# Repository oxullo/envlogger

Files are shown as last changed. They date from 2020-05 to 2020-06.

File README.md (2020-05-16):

# ENVLogger

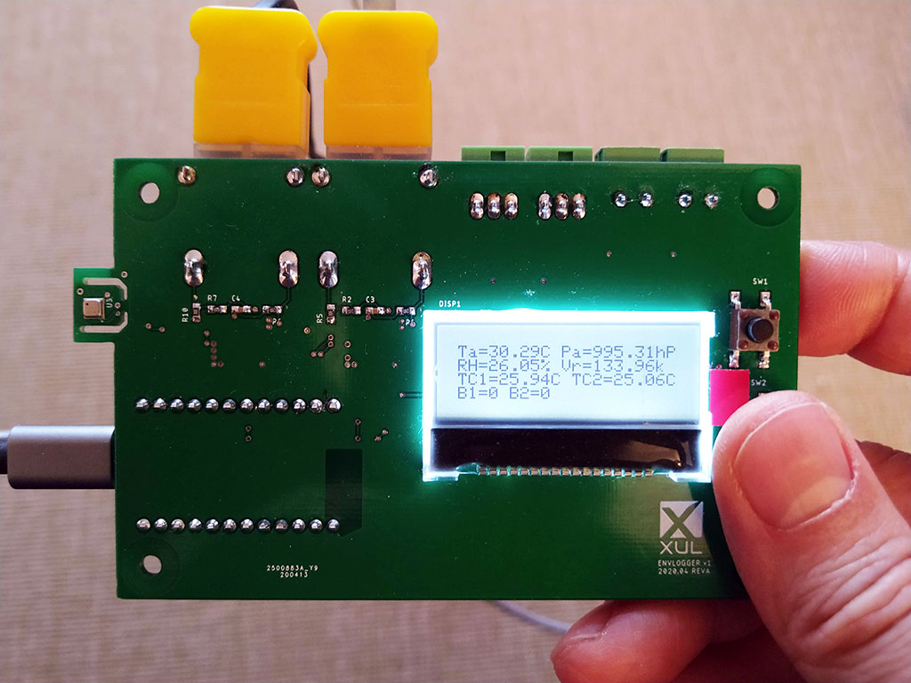
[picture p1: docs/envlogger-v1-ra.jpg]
ENVLogger


Versatile hardware for logging/controlling environmental conditions.

Currently equipping:

* 2x Type-K Thermocouples EMF to digital converters
* Local Bosch-Sensortec BME680 environmental sensor
	* Temperature
	* Humidity
	* Atmospheric pressure
	* Volatile organic compounds
* 2x generic I/Os for additional 1-wire sensors (eg: DS1820B)
* 2x open-drain outputs
* 128x32, backlit FSTN LCD display
* Two buttons

## The article

Most of the information regarding this device can be found here: https://www.xul.it/blog/index.php/2020/05/16/envlogger-v1-rev-a/

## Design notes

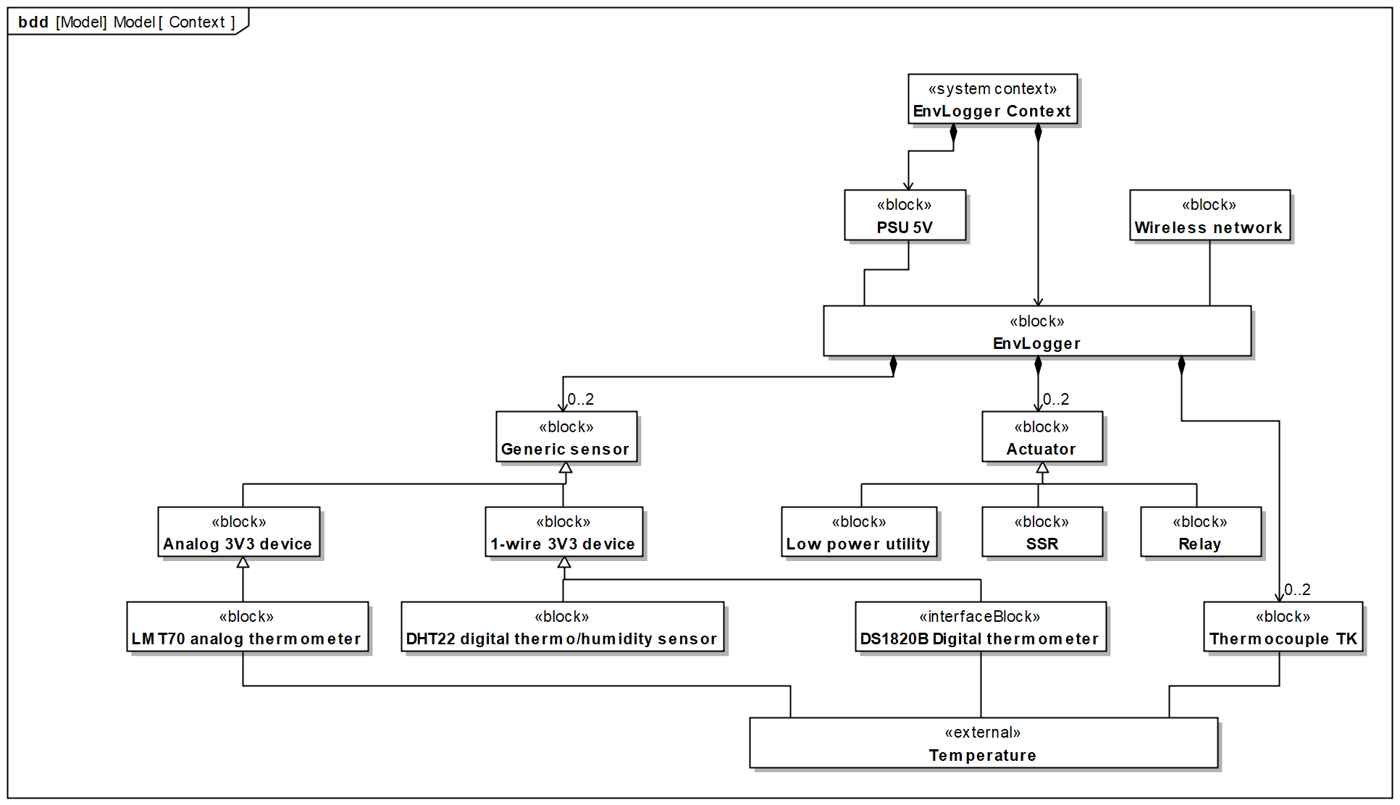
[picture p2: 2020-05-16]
docs/sysml/bdd__Context.png

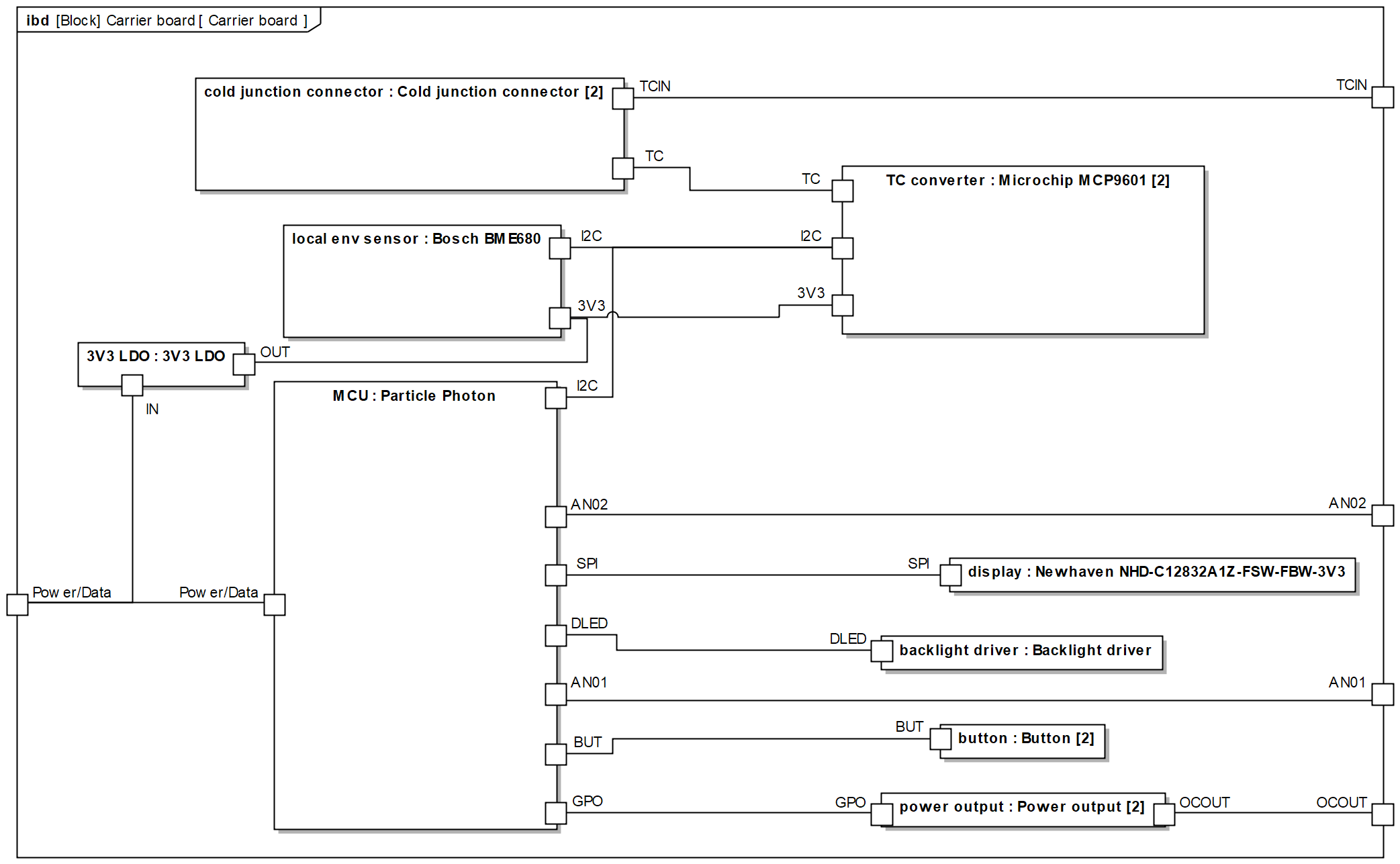
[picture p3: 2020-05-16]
docs/sysml/ibd__Carrier_board__Carrier_board.png

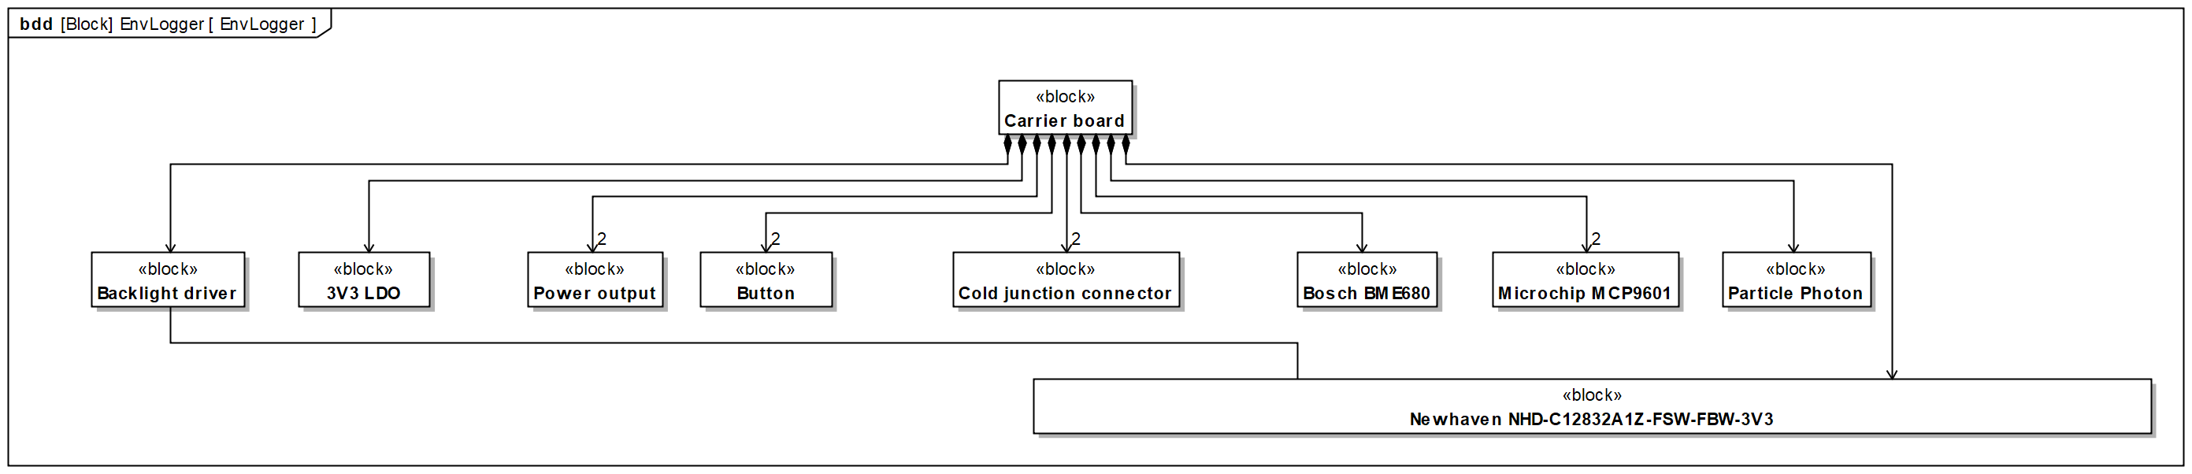
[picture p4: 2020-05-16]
docs/sysml/bdd__EnvLogger__EnvLogger.png

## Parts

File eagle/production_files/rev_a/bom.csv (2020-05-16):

Qty | Value | Device | Package | Parts | Description
4 | 100R | R-EU_R0603 | R0603 | R1, R2, R6, R7 | RESISTOR, European symbol
4 | 100k | R-EU_R0603 | R0603 | R19, R21, R22, R23 | RESISTOR, European symbol
6 | 100n | C-EUC0603 | C0603 | C1, C2, C3, C4, C5, C6 | CAPACITOR, European symbol
2 | 1M | R-EU_R0603 | R0603 | R4, R9 | RESISTOR, European symbol
11 | 1u | C-EUC0603 | C0603 | C7, C8, C9, C10, C11, C12, C13, C14, C15, C16, C17 | CAPACITOR, European symbol
3 | 200 | R-EU_R0603 | R0603 | R13, R14, R18 | RESISTOR, European symbol
4 | 2M | R-EU_R0603 | R0603 | R3, R5, R8, R10 | RESISTOR, European symbol
1 | 330R | R-EU_R0603 | R0603 | R17 | RESISTOR, European symbol
4 | 4k7 | R-EU_R0603 | R0603 | R11, R12, R15, R16 | RESISTOR, European symbol
4 | B5819W | DIODESOD-123 | SOD-123 | D1, D2, D3, D4 | Diode
1 | BME680 | BME680 | BME680 | U3 | Environmental sensor
2 | FSM4JSMA | FSM4JSMA | BUTTON-6MM-SPST | SW1, SW2 | Tactile switch SPST-NO
3 | IRLML0060TRPBF | IRLML0060TRPBF | SOT95P237X112-3N | T1, T2, T3 | N-Channel MOSFET
2 | MC2 | MC2 | MC2 | X5, X6 | Mini-Combicon 3.81mm horizontal 2-polig
2 | MCP9601 | MCP9601 | QFN65P500X500X95-21T325N | U1, U2 | Thermocouple EMF to temperature converter
2 | MCV_05/3-G-2,5 | MCV_05/3-G-2,5 | MC3 | X3, X4 | Mini-Combicon 2.50mm 3polig
1 | MIC5504SOT23-5LD | MIC5504SOT23-5LD | SOT95P280X145-5 | U4 | LDO 3V3 300mA
4 | MOUNT-HOLE3.2 | MOUNT-HOLE3.2 | 3,2 | H1, H2, H3, H4 | MOUNTING HOLE with drill center marker
1 | NHD-C12832A1Z | NHD-C12832A1Z | NHD-C12832A1Z | DISP1
1 | PARTICLE_PHOTON | PARTICLE_PHOTON | PARTICLE_PHOTON | JP1 | Particle Photon
4 | PTR1B1,27 | PTR1B1,27 | B1,27 | TP1, TP2, TP3, TP4 | TEST PIN
1 | PTR1PAD1-13 | PTR1PAD1-13 | P1-13 | TP5 | TEST PIN
2 | PU ENABLE | JUMPER-SMT_2_NC_PASTE_SILK | SMT-JUMPER_2_NC_PASTE_SILK | JP2, JP3 | Normally closed solder jumper
2 | TCCON-PCC-SMP | TCCON-PCC-SMP | TCCON-PCC-SMP | X1, X2 | Thermocouple cold junction IEC miniature connector

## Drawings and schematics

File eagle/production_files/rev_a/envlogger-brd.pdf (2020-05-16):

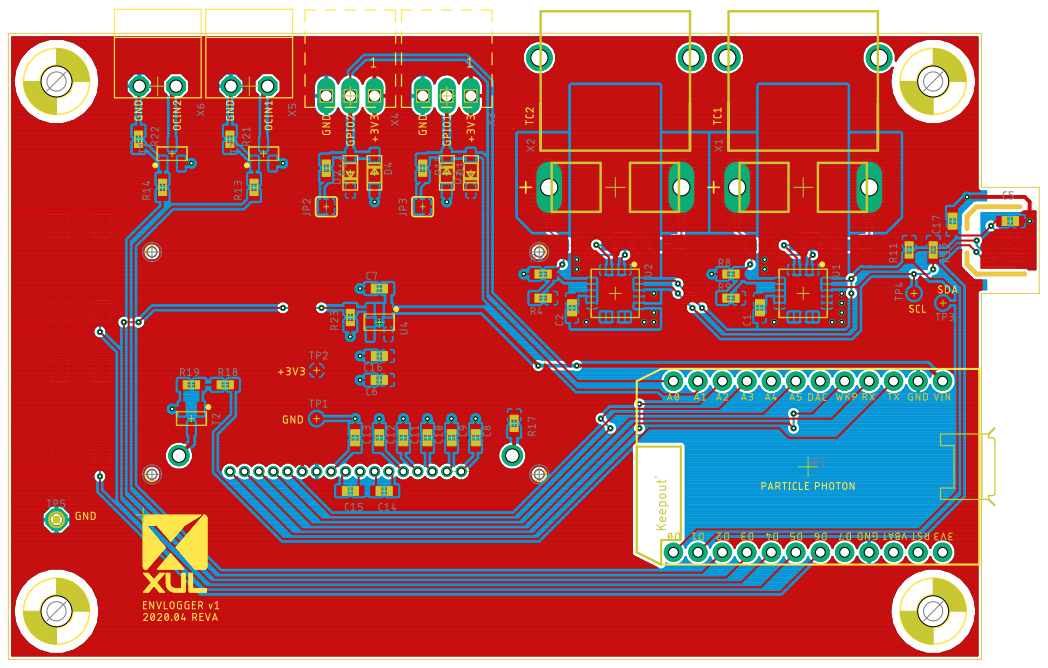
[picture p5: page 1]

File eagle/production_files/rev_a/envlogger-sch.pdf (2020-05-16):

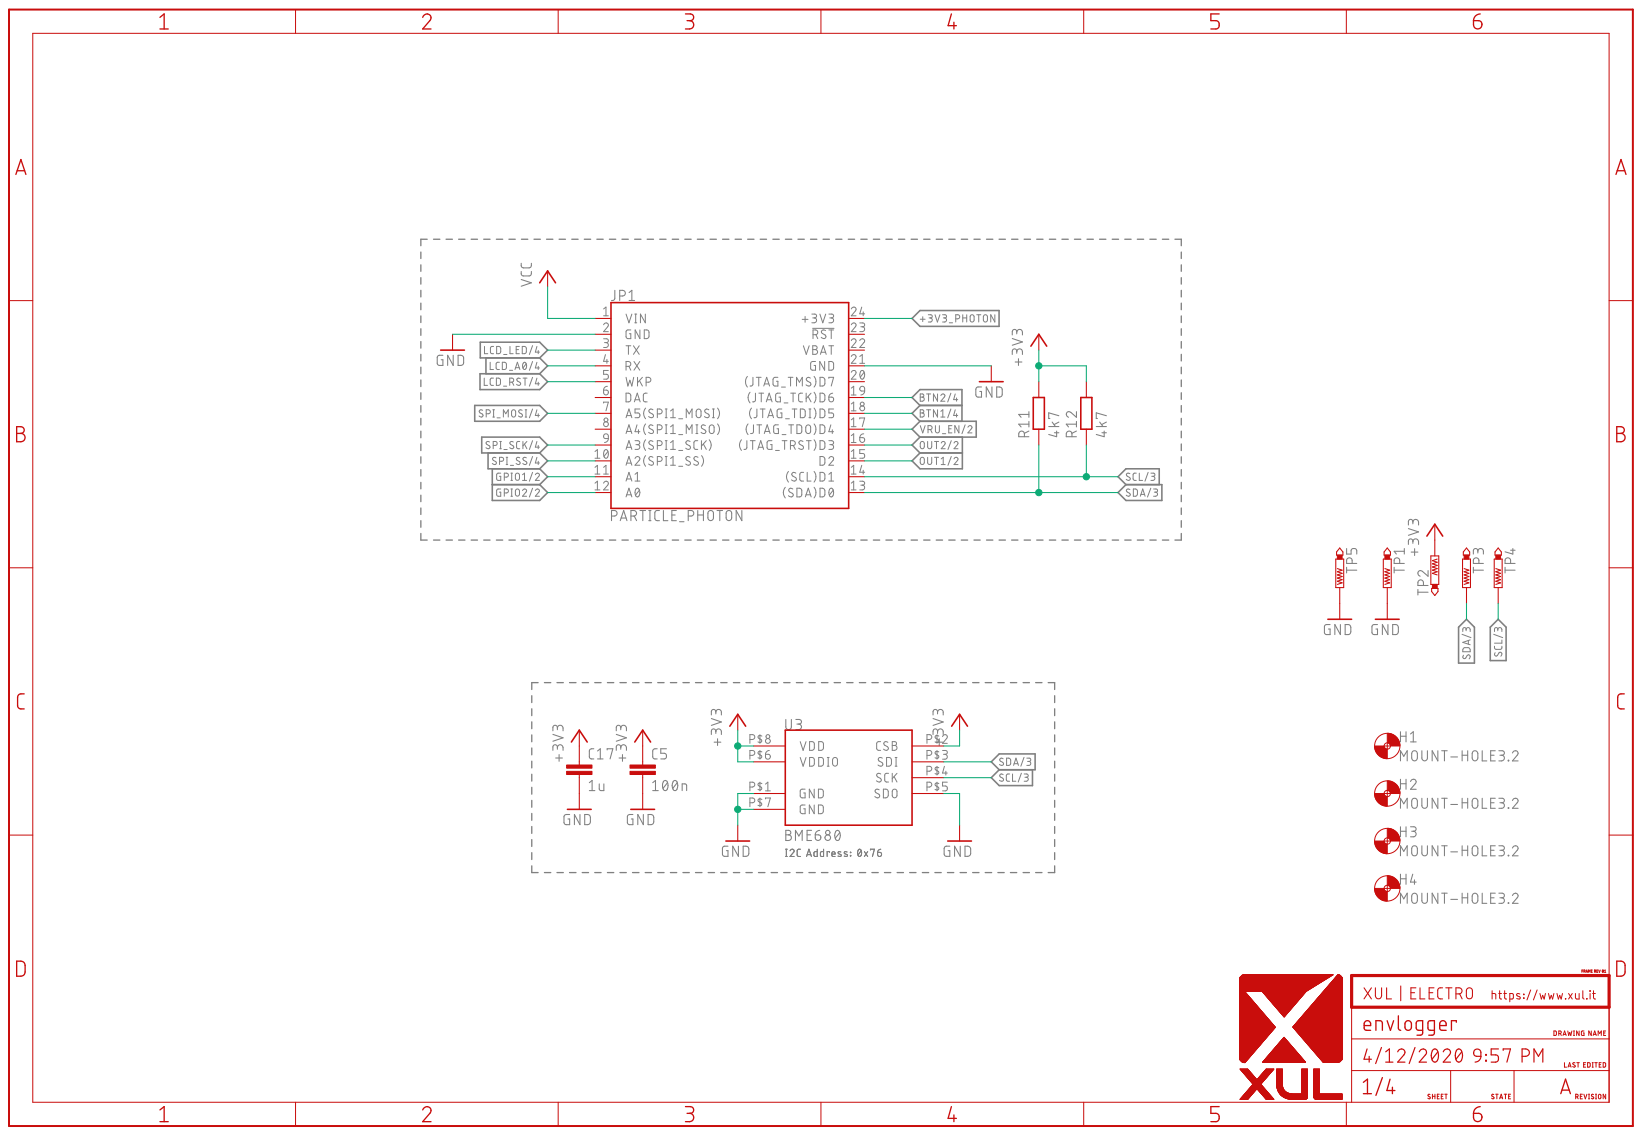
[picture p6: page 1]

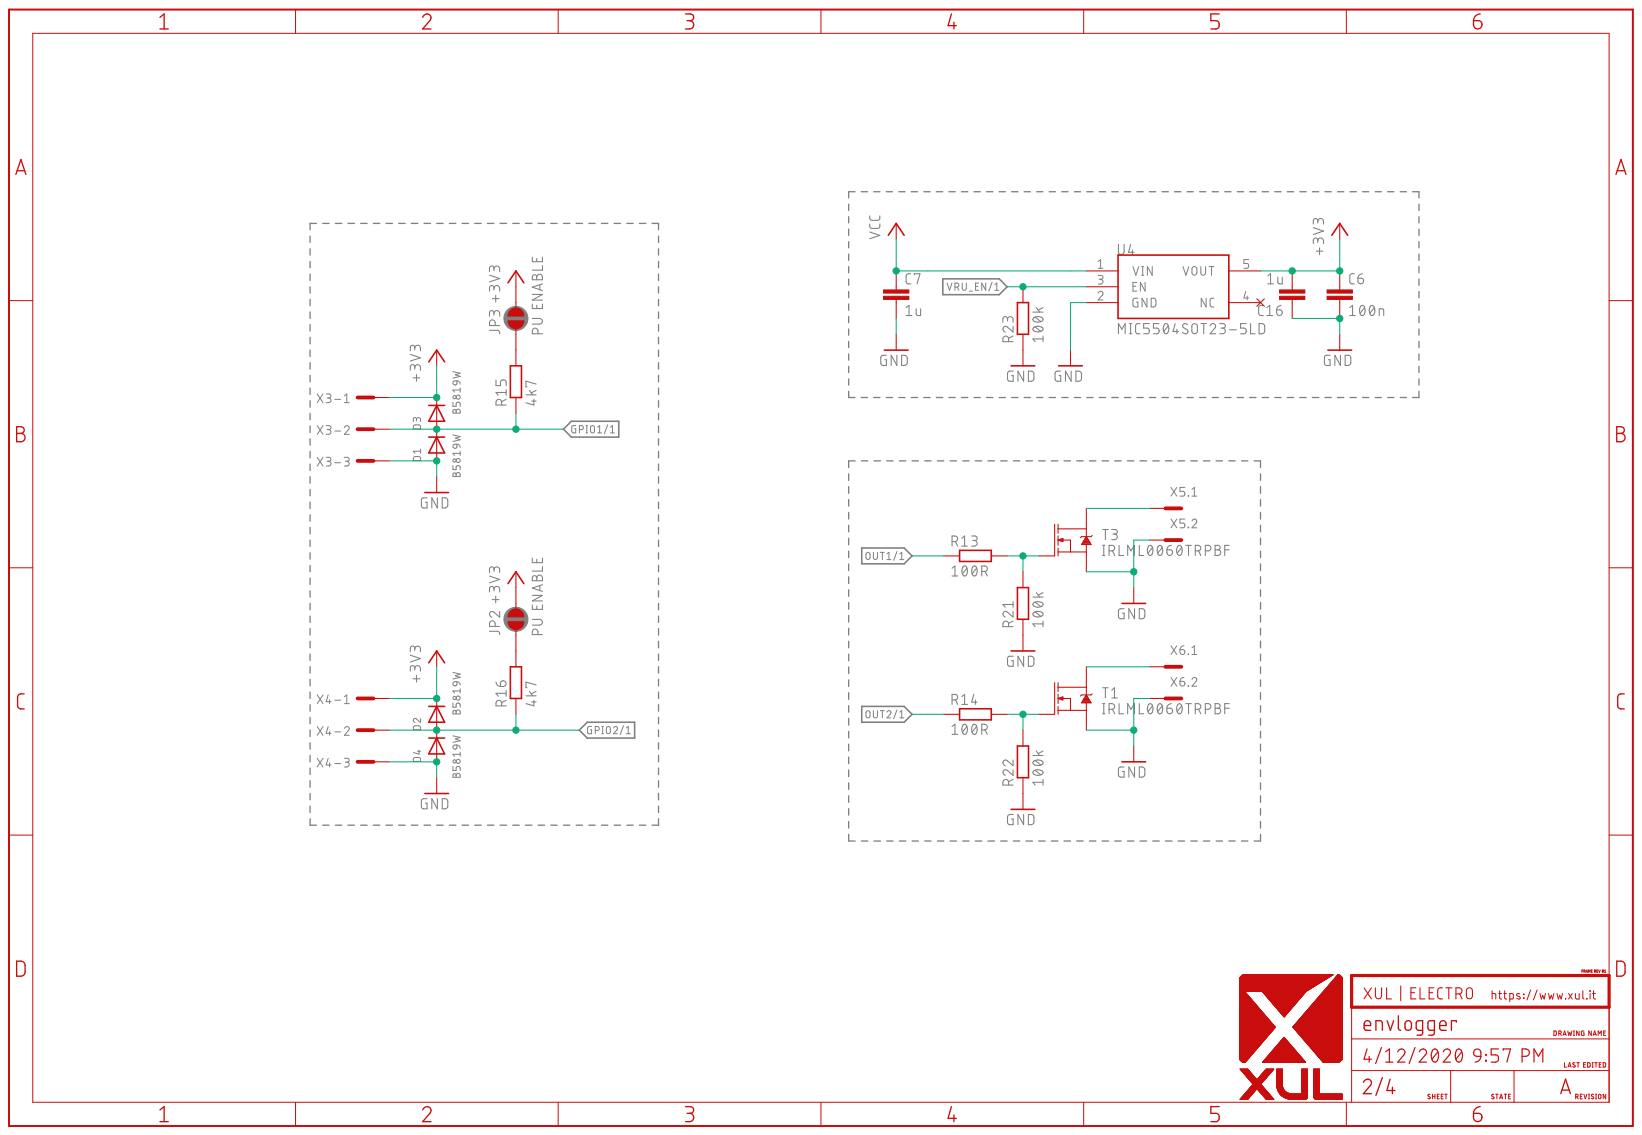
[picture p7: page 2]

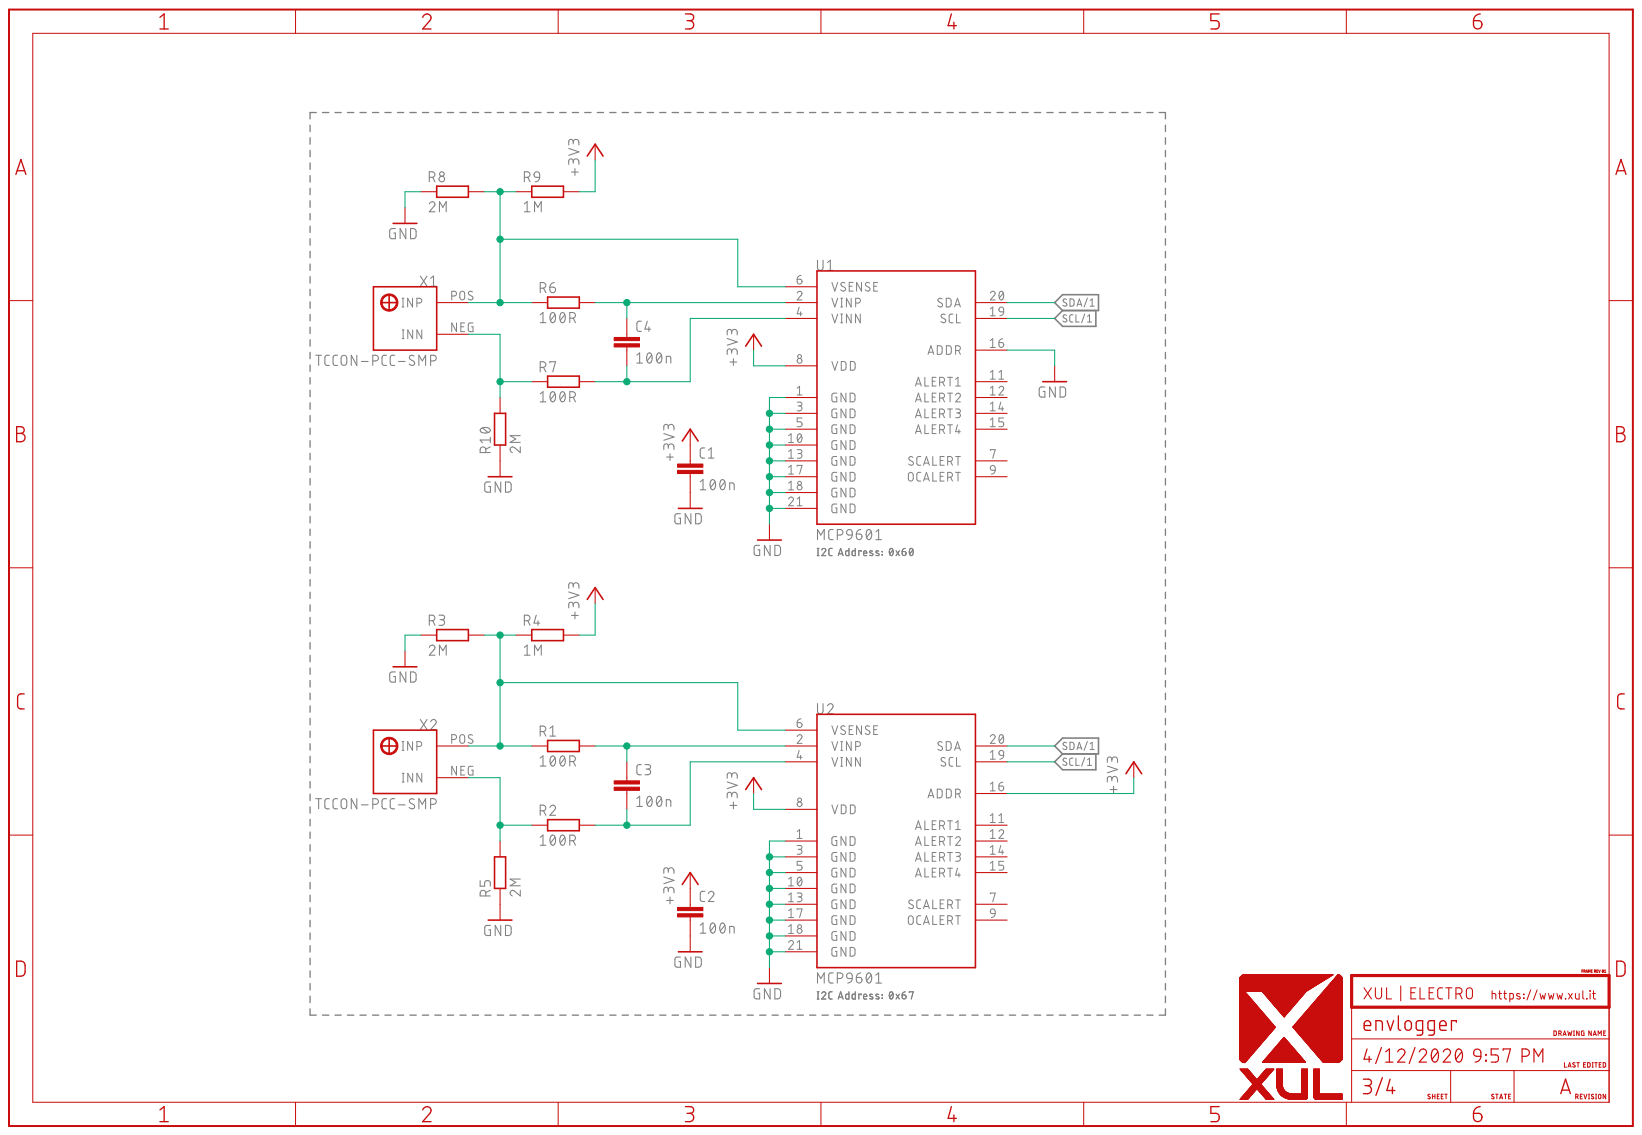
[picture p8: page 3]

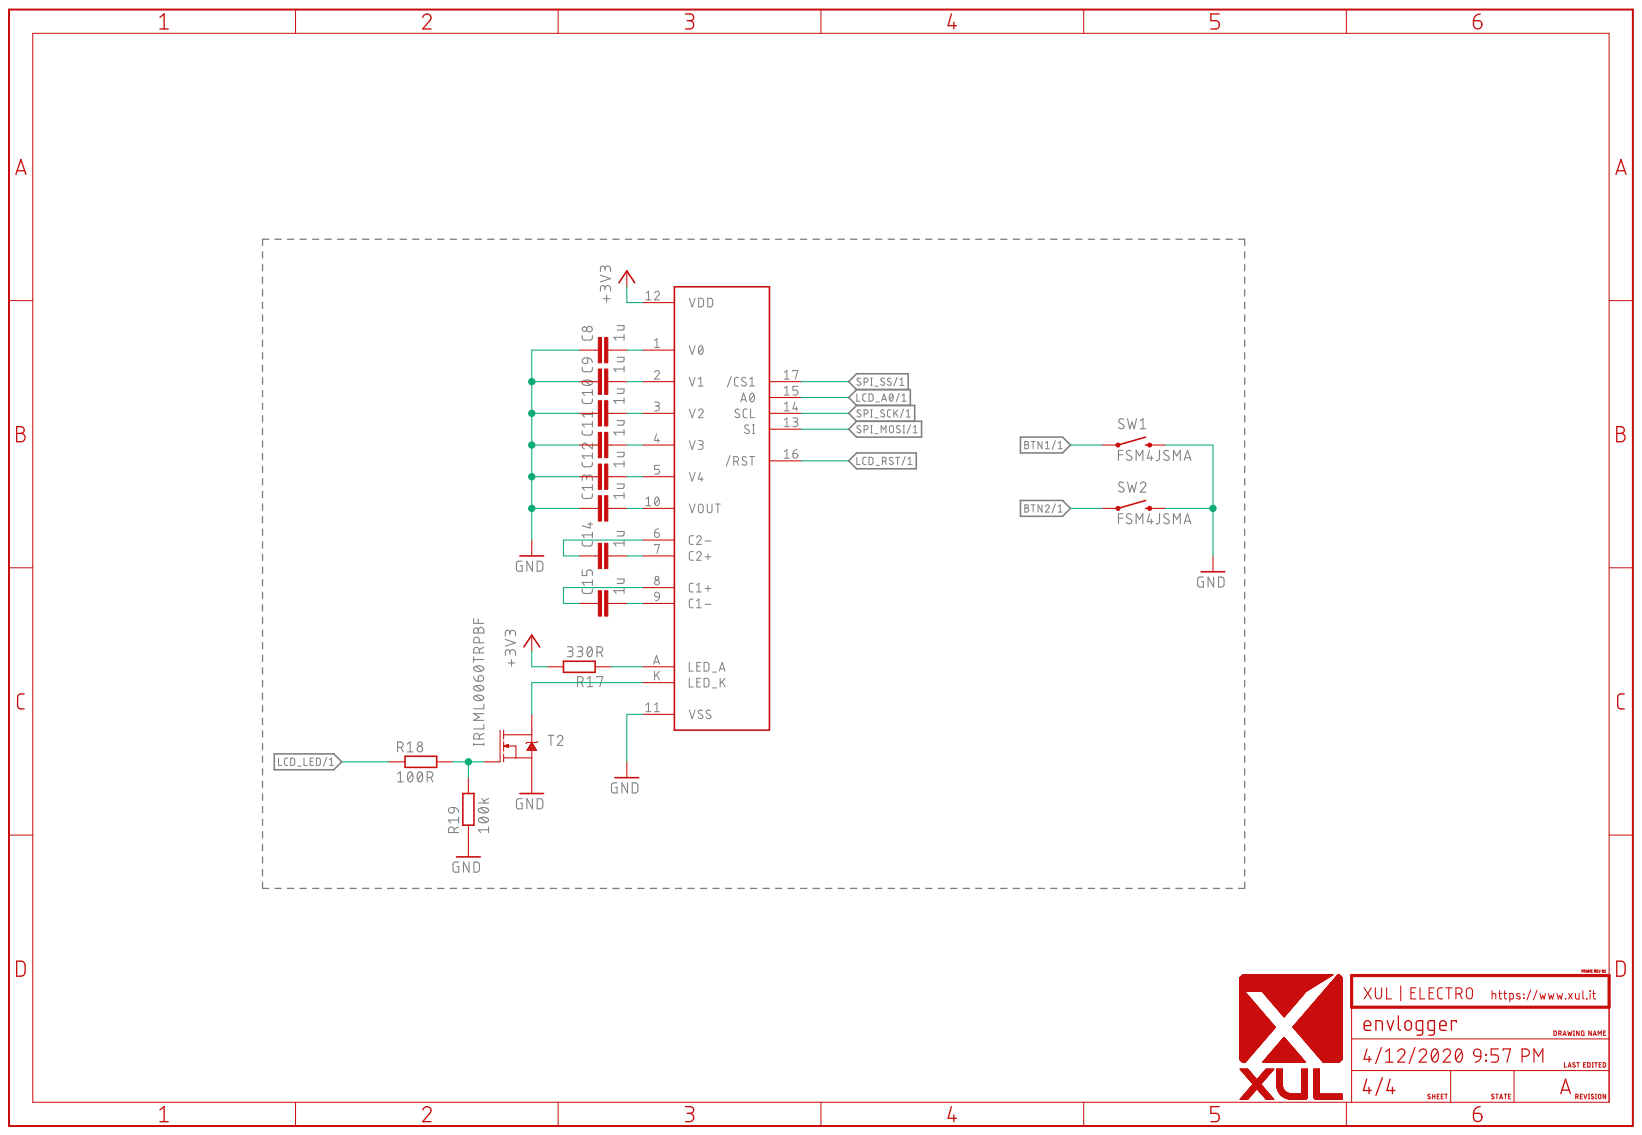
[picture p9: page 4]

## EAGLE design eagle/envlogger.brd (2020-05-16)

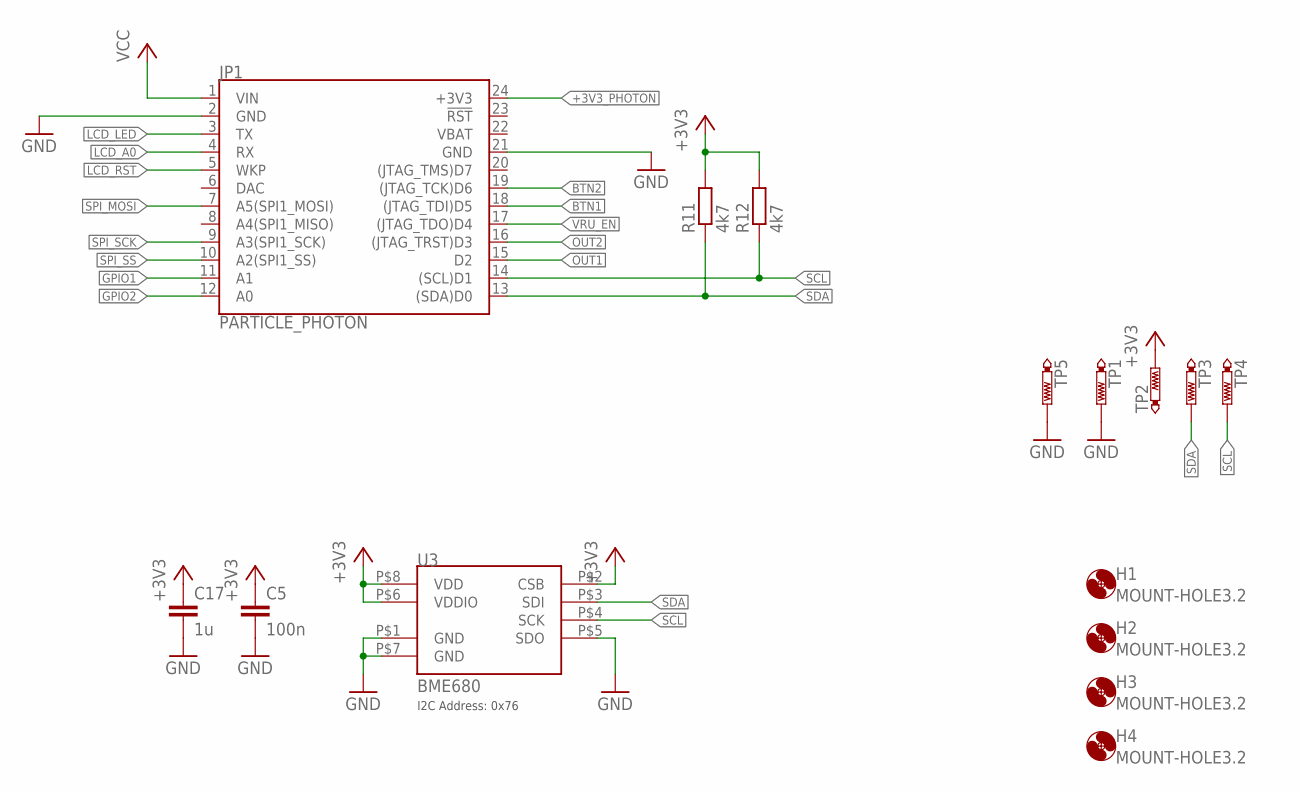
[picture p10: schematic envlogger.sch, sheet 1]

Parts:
C5: 100n; C0603
C17: 1u; C0603
H1, H2, H3, H4: MOUNT-HOLE3.2; 3,2
JP1: PARTICLE_PHOTON
R11, R12: 4k7; R0603
TP1, TP2, TP3, TP4: PTR1B1,27; B1,27
TP5: PTR1PAD1-13; P1-13
U3: BME680

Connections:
+3V3: C5.1, C17.1, R11.2, R12.2, TP2.TP, U3.P$2 (CSB), U3.P$6 (VDDIO), U3.P$8 (VDD); also elsewhere on the board
+3V3_PHOTON: JP1.24 (+3V3)
BTN1: JP1.18 ((JTAG_TDI)D5); also elsewhere on the board
BTN2: JP1.19 ((JTAG_TCK)D6); also elsewhere on the board
GND: C5.2, C17.2, JP1.2 (GND), JP1.21 (GND), TP1.TP, TP5.TP, U3.P$1 (GND), U3.P$5 (SDO), U3.P$7 (GND); also elsewhere on the board
GPIO1: JP1.11 (A1); also elsewhere on the board
GPIO2: JP1.12 (A0); also elsewhere on the board
LCD_A0: JP1.4 (RX); also elsewhere on the board
LCD_LED: JP1.3 (TX); also elsewhere on the board
LCD_RST: JP1.5 (WKP); also elsewhere on the board
OUT1: JP1.15 (D2); also elsewhere on the board
OUT2: JP1.16 ((JTAG_TRST)D3); also elsewhere on the board
SCL: JP1.14 ((SCL)D1), R12.1, TP4.TP, U3.P$4 (SCK); also elsewhere on the board
SDA: JP1.13 ((SDA)D0), R11.1, TP3.TP, U3.P$3 (SDI); also elsewhere on the board
SPI_MOSI: JP1.7 (A5(SPI1_MOSI)); also elsewhere on the board
SPI_SCK: JP1.9 (A3(SPI1_SCK)); also elsewhere on the board
SPI_SS: JP1.10 (A2(SPI1_SS)); also elsewhere on the board
VBAT: JP1.22 (VBAT)
VCC: JP1.1 (VIN); also elsewhere on the board
VRU_EN: JP1.17 ((JTAG_TDO)D4); also elsewhere on the board

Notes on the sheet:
I2C Address: 0x76

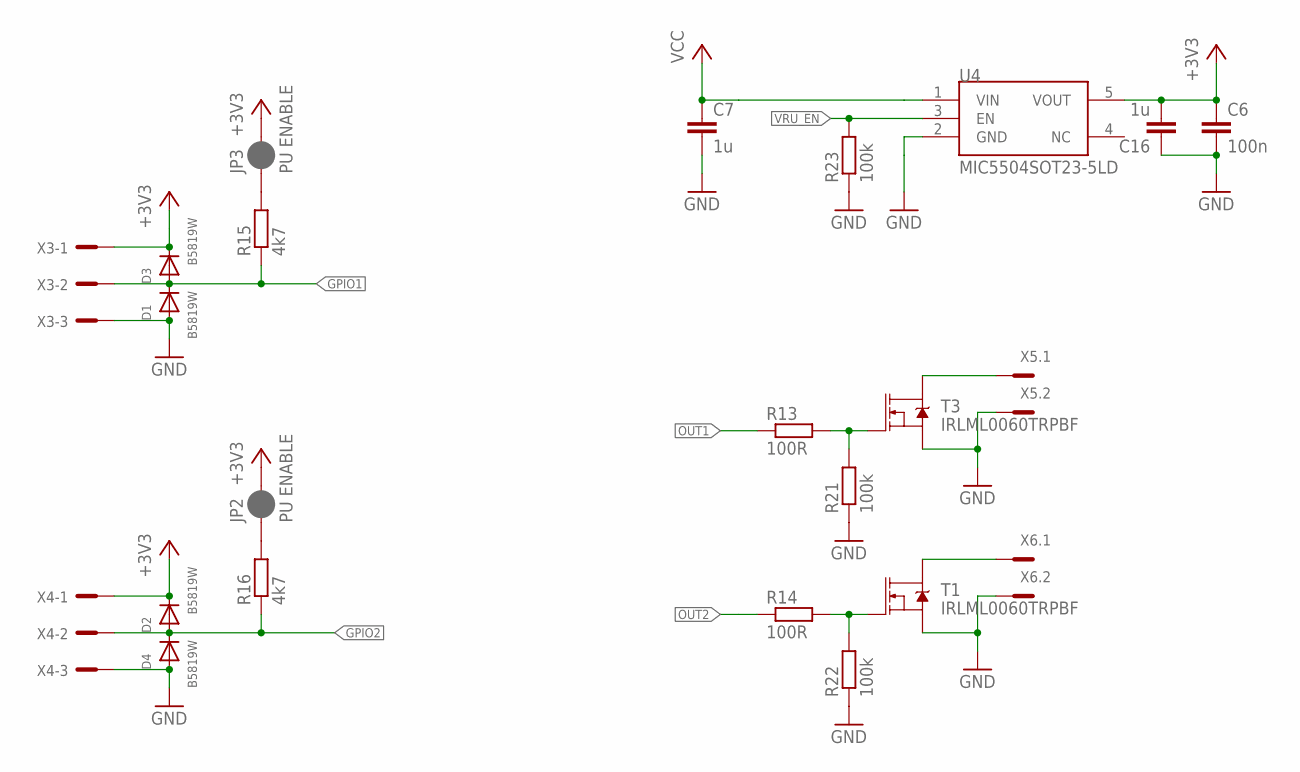
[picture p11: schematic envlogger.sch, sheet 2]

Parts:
C6: 100n; C0603
C7, C16: 1u; C0603
D1, D2, D3, D4: B5819W; SOD-123
JP2, JP3: PU ENABLE; SMT-JUMPER_2_NC_PASTE_SILK
R13, R14: 100R; R0603
R15, R16: 4k7; R0603
R21, R22, R23: 100k; R0603
T1, T3: IRLML0060TRPBF; SOT95P237X112-3N
U4: MIC5504SOT23-5LD; SOT95P280X145-5
X3, X4: MCV_05/3-G-2,5; MC3
X5, X6: MC2

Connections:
+3V3: C6.1, C16.2, D2.C, D3.C, JP2.2, JP3.2, U4.5 (VOUT), X3.1, X4.1; also elsewhere on the board
GND: C6.2, C7.2, C16.1, D1.A, D4.A, R21.1, R22.1, R23.1, T1.2 (S), T3.2 (S), U4.2 (GND), X3.3, X4.3, X5.2, X6.2; also elsewhere on the board
GPIO1: D1.C, D3.A, R15.1, X3.2; also elsewhere on the board
GPIO2: D2.A, D4.C, R16.1, X4.2; also elsewhere on the board
unnamed: T3.3 (D), X5.1
unnamed: R13.2, R21.2, T3.1 (G)
unnamed: T1.3 (D), X6.1
unnamed: R14.2, R22.2, T1.1 (G)
unnamed: JP2.1, R16.2
unnamed: JP3.1, R15.2
OUT1: R13.1; also elsewhere on the board
OUT2: R14.1; also elsewhere on the board
VCC: C7.1, U4.1 (VIN); also elsewhere on the board
VRU_EN: R23.2, U4.3 (EN); also elsewhere on the board

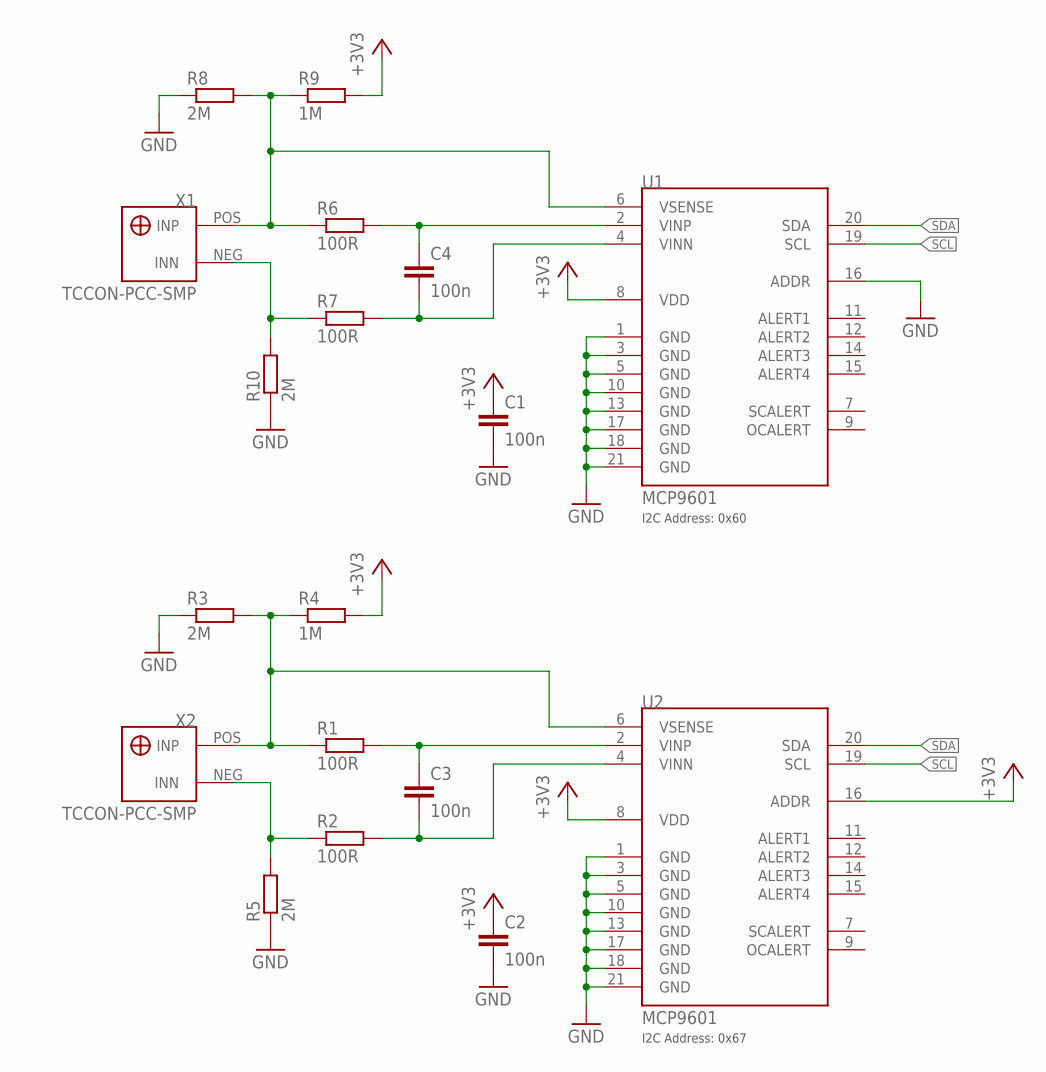
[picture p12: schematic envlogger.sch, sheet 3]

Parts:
C1, C2, C3, C4: 100n; C0603
R1, R2, R6, R7: 100R; R0603
R3, R5, R8, R10: 2M; R0603
R4, R9: 1M; R0603
U1, U2: MCP9601; QFN65P500X500X95-21T325N
X1, X2: TCCON-PCC-SMP

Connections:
+3V3: C1.1, C2.1, R4.2, R9.2, U1.8 (VDD), U2.8 (VDD), U2.16 (ADDR); also elsewhere on the board
GND: C1.2, C2.2, R3.1, R5.1, R8.1, R10.1, U1.1 (GND), U1.3 (GND), U1.5 (GND), U1.10 (GND), U1.13 (GND), U1.16 (ADDR), U1.17 (GND), U1.18 (GND), U1.21 (GND), U2.1 (GND), U2.3 (GND), U2.5 (GND), U2.10 (GND), U2.13 (GND), U2.17 (GND), U2.18 (GND), U2.21 (GND); also elsewhere on the board
unnamed: R1.1, R3.2, R4.1, U2.6 (VSENSE), X2.POS (INP)
unnamed: R2.1, R5.2, X2.NEG (INN)
unnamed: C3.2, R2.2, U2.4 (VINN)
unnamed: C3.1, R1.2, U2.2 (VINP)
unnamed: R6.1, R8.2, R9.1, U1.6 (VSENSE), X1.POS (INP)
unnamed: R7.1, R10.2, X1.NEG (INN)
unnamed: C4.2, R7.2, U1.4 (VINN)
unnamed: C4.1, R6.2, U1.2 (VINP)
SCL: U1.19 (SCL), U2.19 (SCL); also elsewhere on the board
SDA: U1.20 (SDA), U2.20 (SDA); also elsewhere on the board

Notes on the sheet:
I2C Address: 0x60
I2C Address: 0x67

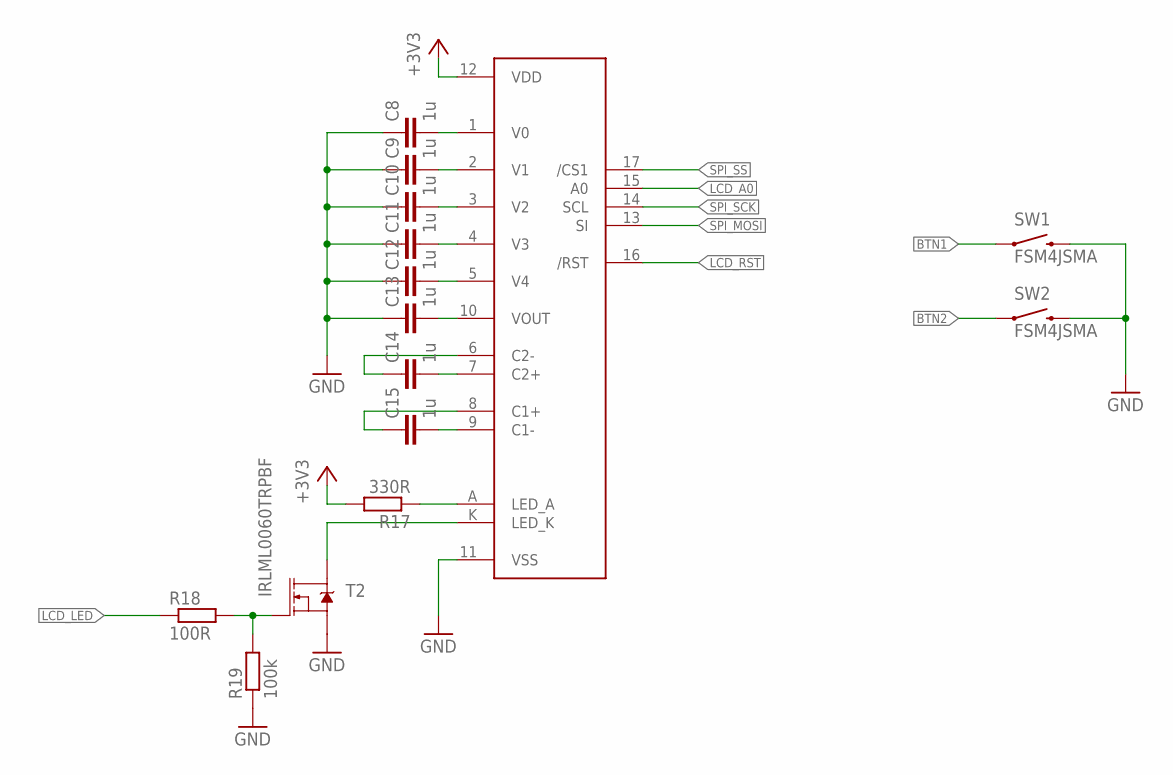
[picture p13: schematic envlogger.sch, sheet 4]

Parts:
C8, C9, C10, C11, C12, C13, C14, C15: 1u; C0603
DISP1: NHD-C12832A1Z
R17: 330R; R0603
R18: 100R; R0603
R19: 100k; R0603
SW1, SW2: FSM4JSMA; BUTTON-6MM-SPST
T2: IRLML0060TRPBF; SOT95P237X112-3N

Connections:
+3V3: DISP1.12 (VDD), R17.2; also elsewhere on the board
BTN1: SW1.P$1 (1); also elsewhere on the board
BTN2: SW2.P$1 (1); also elsewhere on the board
GND: C8.1, C9.1, C10.1, C11.1, C12.1, C13.1, DISP1.11 (VSS), R19.1, SW1.P$4 (2), SW2.P$4 (2), T2.2 (S); also elsewhere on the board
LCD_A0: DISP1.15 (A0); also elsewhere on the board
LCD_LED: R18.1; also elsewhere on the board
LCD_RST: DISP1.16 (/RST); also elsewhere on the board
unnamed: DISP1.A (LED_A), R17.1
unnamed: R18.2, R19.2, T2.1 (G)
unnamed: DISP1.K (LED_K), T2.3 (D)
unnamed: C8.2, DISP1.1 (V0)
unnamed: C9.2, DISP1.2 (V1)
unnamed: C10.2, DISP1.3 (V2)
unnamed: C11.2, DISP1.4 (V3)
unnamed: C12.2, DISP1.5 (V4)
unnamed: C13.2, DISP1.10 (VOUT)
unnamed: C14.2, DISP1.7 (C2+)
unnamed: C15.2, DISP1.9 (C1-)
unnamed: C14.1, DISP1.6 (C2-)
unnamed: C15.1, DISP1.8 (C1+)
SPI_MOSI: DISP1.13 (SI); also elsewhere on the board
SPI_SCK: DISP1.14 (SCL); also elsewhere on the board
SPI_SS: DISP1.17 (/CS1); also elsewhere on the board

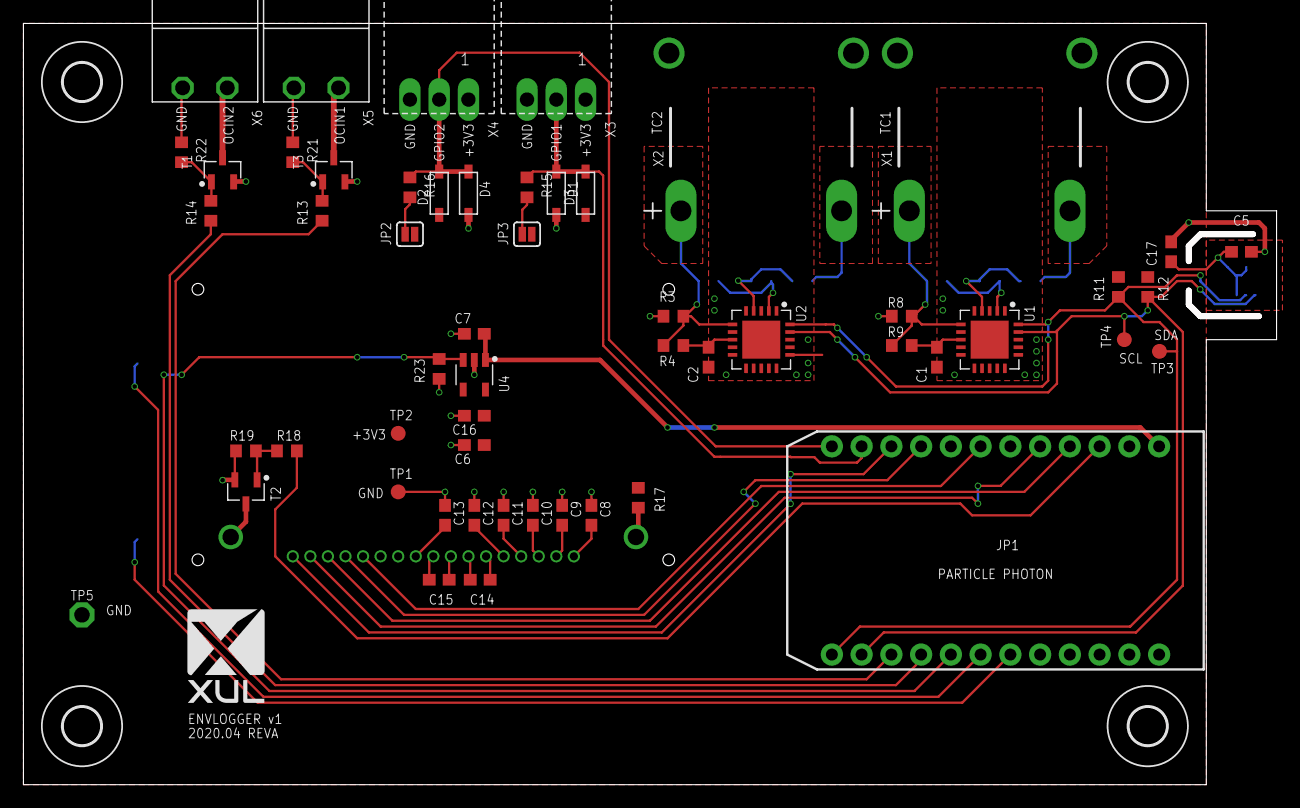
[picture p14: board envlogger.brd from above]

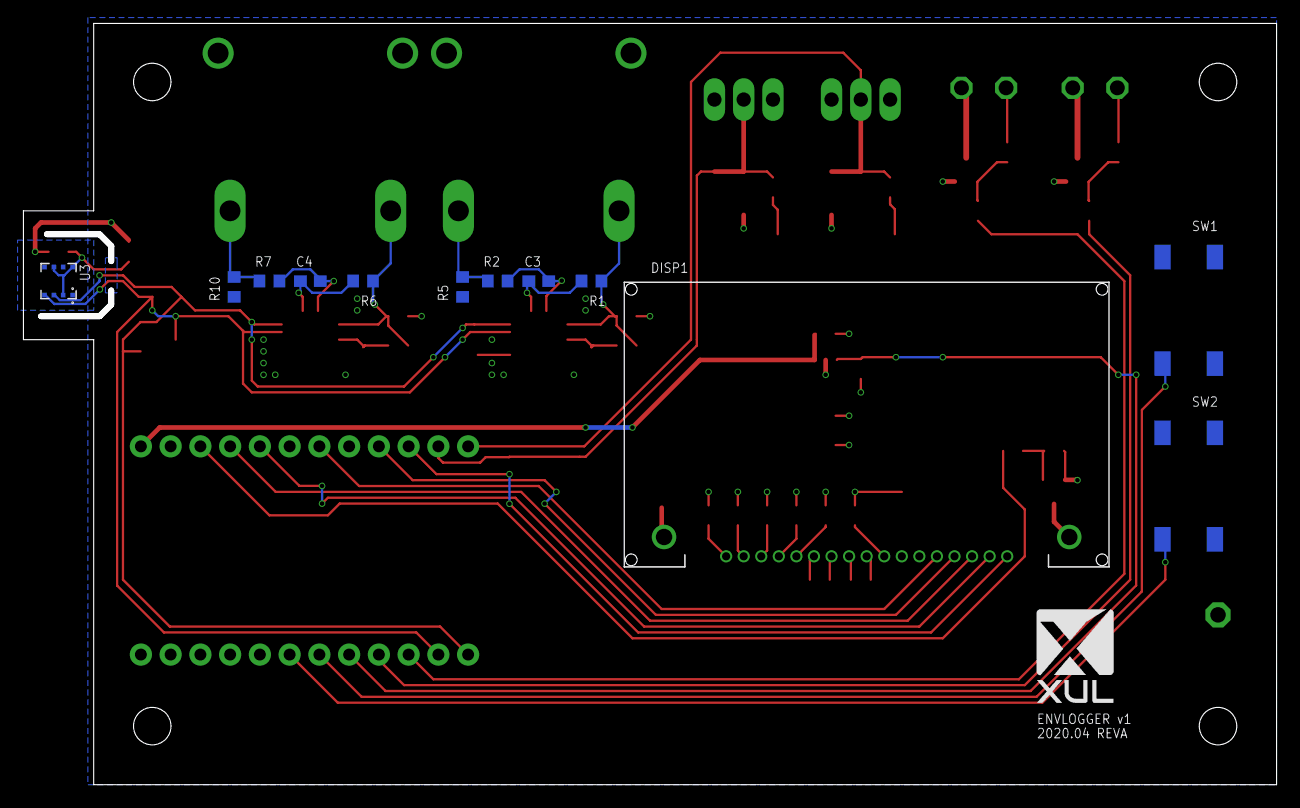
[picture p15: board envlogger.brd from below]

Board: 2 copper layers, 107.0 x 65.0 mm, 73 parts (13 on the bottom side), 45 nets.

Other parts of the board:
U$1, U$2: XUL-LOGO-8MMH

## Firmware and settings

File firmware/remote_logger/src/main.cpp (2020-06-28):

// Copyright (c) 2020 OXullo Intersecans <x@brainrapers.org>
//
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
#include <Particle.h>

#include "envsensor.h"
#include "mcp9601.h"
#include "ui.h"
#include "reporter.h"

const uint8_t VRU_ENABLE_PIN = 4;


SYSTEM_MODE(SEMI_AUTOMATIC);
SYSTEM_THREAD(ENABLED);

void enable_system_power()
{
    pinMode(VRU_ENABLE_PIN, OUTPUT);
    digitalWrite(VRU_ENABLE_PIN, HIGH);
    delay(500);
}

void setup()
{
    Wire.begin();
    Serial.begin(9600);
    
    enable_system_power();

    envsensor_init(false);
    mcp9601_init();
    ui_init();
    ui_connect_network();
}

void loop()
{
    envsensor_update();
    mcp9601_update();
    reporter_update();

    envsensor_dump();
    mcp9601_dump();

    Serial.println("--------");

    ui_update();
}

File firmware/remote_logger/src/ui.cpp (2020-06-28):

// Copyright (c) 2020 OXullo Intersecans <x@brainrapers.org>
//
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
#include <stdint.h>
#include <Particle.h>

#include <ADAFRUIT_ST7565.h>

#include "ui.h"
#include "envsensor.h"
#include "mcp9601.h"

static const uint8_t LCD_SI_PIN = A5;
static const uint8_t LCD_SCL_PIN = A3;
static const uint8_t LCD_A0_PIN = RX;
static const uint8_t LCD_RST_PIN = WKP;
static const uint8_t LCD_CS1_PIN = A2;

static const uint8_t LCD_BLIGHT_PIN = TX;

static const uint8_t BUTTON1_PIN = 5;
static const uint8_t BUTTON2_PIN = 6;

static const uint32_t BACKLIGHT_OFF_PERIOD = 10000;

#define ST7565_HSPI


static ST7565 glcd(LCD_SI_PIN, LCD_SCL_PIN, LCD_A0_PIN, LCD_RST_PIN, LCD_CS1_PIN);
static uint32_t ts_last_press = 0;


void ui_backlight_enable(bool on)
{
    if (on) {
        for (uint8_t i=0 ; i < 255 ; ++i) {
            analogWrite(LCD_BLIGHT_PIN, i);
            delay(1);
        }
        analogWrite(LCD_BLIGHT_PIN, 255);
    } else {
        for (uint8_t i=255 ; i > 0 ; --i) {
            analogWrite(LCD_BLIGHT_PIN, i);
            delay(1);
        }
        analogWrite(LCD_BLIGHT_PIN, 0);
    }
}

void check_backlight()
{
    if (ts_last_press && millis() - ts_last_press > BACKLIGHT_OFF_PERIOD) {
        ui_backlight_enable(false);
        ts_last_press = 0;
    }
}

void ui_init()
{
    pinMode(BUTTON1_PIN, INPUT_PULLUP);
    pinMode(BUTTON2_PIN, INPUT_PULLUP);

    pinMode(LCD_BLIGHT_PIN, OUTPUT);
    ui_backlight_enable(true);

    glcd.begin(0x25);
    glcd.clear();
    glcd.drawstring(0, 0, "ENVLOGGER v1");
    glcd.drawstring(0, 1, "Remote logger");
    glcd.display();

    delay(1500);
}

void ui_connect_network()
{
    String s;
    byte mac[6];

    WiFi.on();

    WiFi.connect(WIFI_CONNECT_SKIP_LISTEN);
    char spinner[] = {'/', '-', '\\', '|'};
    uint8_t i = 0;

    glcd.clear();
    while(!WiFi.ready()) {
        glcd.drawstring(0, 0, "WiFi link.." + String(spinner[i]));
        i = (i + 1) % 4;
        glcd.display();
        delay(200);
    }

    glcd.drawstring(0, 0, "WiFi link: OK");
    glcd.display();
    delay(500);

    WiFi.macAddress(mac);
    s = "MAC:" + String(mac[0], HEX) + ":"
        + String(mac[1], HEX) + ":"
        + String(mac[2], HEX) + ":"
        + String(mac[3], HEX) + ":"
        + String(mac[4], HEX) + ":"
        + String(mac[5], HEX);

    glcd.clear();
    glcd.drawstring(0, 0, s);
    glcd.drawstring(0, 1, "SSID:" + String(WiFi.SSID()));
    glcd.drawstring(0, 2, "RSSI:" + String(WiFi.RSSI()));
    glcd.drawstring(0, 3, "IP:" + String(WiFi.localIP()));
    glcd.display();

    delay(3000);
    ts_last_press = millis();
}

void ui_update()
{
    glcd.clear();
    String s;
    TCData* tcd;

    s = String("Ta=") + String(envsensor_get_ta(), 2) + "C Pa=" + String(envsensor_get_pa(), 2) + "hPa"; 
    glcd.drawstring(0, 0, s.c_str());

    s = String("RH=") + String(envsensor_get_rh(), 2) + "% Vr=" + String(envsensor_get_vocr(), 2) + "k"; 
    glcd.drawstring(0, 1, s.c_str());

    s = String("TC1=");    
    tcd = mcp9601_get_tcdata(0);
    s += tcd->valid ? (String(tcd->temperature, 2) + "C") : "N/A";
    s += " TC2=";
    tcd = mcp9601_get_tcdata(1);
    s += tcd->valid ? (String(tcd->temperature, 2) + "C") : "N/A";
    glcd.drawstring(0, 2, s.c_str());

    s = String("B1=") + digitalRead(BUTTON1_PIN) + " B2=" + digitalRead(BUTTON2_PIN) + " NET=" + (WiFi.ready() ? "OK" : "NOK");
    glcd.drawstring(0, 3, s.c_str());

    glcd.display();

    if (digitalRead(BUTTON1_PIN) == LOW || digitalRead(BUTTON2_PIN) == LOW) {
        if (ts_last_press == 0) {
            ui_backlight_enable(true);
        }
        ts_last_press = millis();
    }

    check_backlight();
}

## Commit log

2020-05-16 Initial import of schematics and board layout
    [envlogger.brd, envlogger.sch]
2020-05-16 Add production data for hardware revision A
    [bom.csv]
2020-06-28 Proper handling of MCPs ThUPDATE and subsequent error handling, split update and dump
    [main.cpp, ui.cpp]
2020-06-28 Use the slowest filtering options for the BME680
2020-06-28 Add a docker-compose sample configuration

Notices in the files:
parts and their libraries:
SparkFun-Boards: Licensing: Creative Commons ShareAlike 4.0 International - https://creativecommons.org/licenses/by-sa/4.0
